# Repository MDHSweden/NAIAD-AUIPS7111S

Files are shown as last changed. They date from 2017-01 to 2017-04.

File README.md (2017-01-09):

# AUIPS7111S

> The [AUIPS7111S](http://www.farnell.com/datasheets/1441780.pdf) is a fully protected four terminal high
> side switch. It features current sensing, over-current, over-
> temperature, ESD protection and drain to source active
> clamp. When the input voltage Vcc - Vin is higher than the
> specified threshold, the output power Mosfet is turned on.
> When the Vcc - Vin is lower than the specified Vil
> threshold, the output Mosfet
> is turned off. The Ifb pin is
> used for current sensing.

## AUIPS7111S Test curcuit

This is a prototype sub part of PDB.

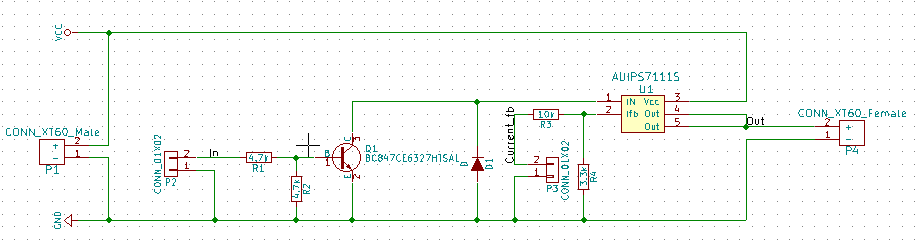
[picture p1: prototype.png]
Image of prototype


The voltage across R4 is `V_R4 = R_4 * I_fb`. So we can configurate the R4 to set the current sense voltage propotional constant to current draw.

`V_R4 = R_4 * I_VCC_Out / Ratio`

### Parts

| Part  | Function  |
|-----|---|
| P1  | Power input |
| P4  | Power output  |
| R1  | Current limiter for BJT. Prevent destroying the BJT or waste power.  |
| R2  | Passive pull down for BJT. We want to make sure the U1 is passively off in case of signal `In` is high impedance.  |
| D1  | Protection for BJT in case of reverse current.  |
| U1  | Switch, current sensing.  |
| R4  | Voltage gain for current sensing. Resistance from `I_fb` to `GND` is max 1.5k [datasheet](http://www.farnell.com/datasheets/1441780.pdf)  |
| R3  | Protection for U1. Resistance from `I_fb` to `GND` is max 1.5k [datasheet](http://www.farnell.com/datasheets/1441780.pdf)  |
| P2  | Input. Connector to control the U1. |
| P3  | Output. Current feedback. |

### Truth table
| `P2_In`  | `U1`  |
|---|---|
| High | On |
| Low | Off |
| High impedance | Off |

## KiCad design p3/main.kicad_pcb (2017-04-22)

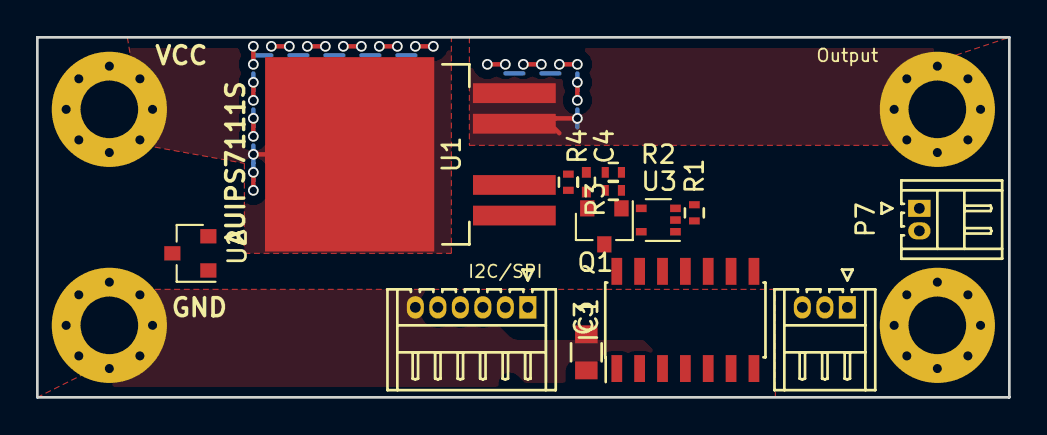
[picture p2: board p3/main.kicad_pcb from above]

Board: 2 copper layers, 54.0 x 20.0 mm, 18 parts (0 on the bottom side), 15 nets.

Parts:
C3: 10uF; C_0805
C4: 1uF; C_0402
IC1: ATTINY84-S; SOIC-14_3.9x8.7mm_Pitch1.27mm
P1, P4, P5, P6: CONN_01X01; MountingHole_3.2mm_M3_Pad_Via
P2: CONN_01X06; Hirose_DF13-06P-1.25DS_06x1.25mm_Angled
P3: CONN_01X03; Hirose_DF13-03P-1.25DS_03x1.25mm_Angled
P7: CONN_01X02; Hirose_DF13-02P-1.25DS_02x1.25mm_Angled
Q1: BSS138; SOT-23
R1, R2: 4.7k; R_0402
R3: 10k; R_0402
R4: 3.3k; R_0402
U1: AUIPS7111S; TO-263-!3
U2: LM3480-5.0; SOT-23
U3: 74LVC1G08; SOT-353

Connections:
+5V: C3.1, IC1.1, P2.5, P3.2, U2.1, U3.5
/Current_Feedback: IC1.12, R3.1
/ENB1: IC1.10, U3.1
/ENB2: P3.3, R1.1, U3.2
/IN: Q1.3, U1.1
/Ifb: C4.1, R3.2, R4.1, U1.2
/MISO: IC1.8, P2.3
/Out: P5.1, U1.4, U1.5
/PWM1: IC1.5, P7.2
/RESET: IC1.4, P2.2
/SCL/SCK: IC1.9, P2.4
/SDA/MOSI: IC1.7, P2.1
GND: C3.2, C4.2, IC1.14, P2.6, P3.1, P4.1, P6.1, P7.1, Q1.2, R1.2, R2.2, R4.2, U2.3, U3.3
unnamed: Q1.1, R2.1, U3.4
VCC: P1.1, U1.3, U2.2

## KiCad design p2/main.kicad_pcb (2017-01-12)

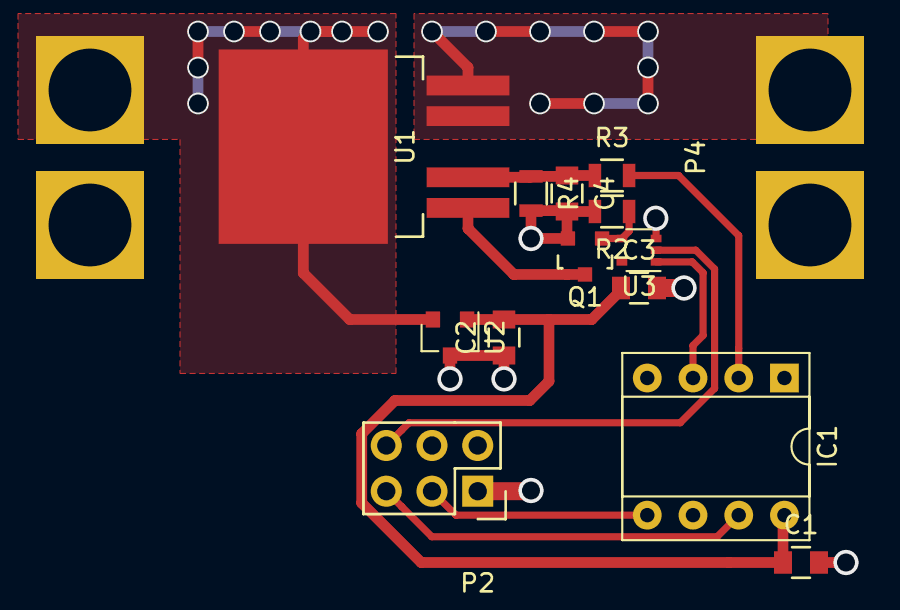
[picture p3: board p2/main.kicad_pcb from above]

Board: 2 copper layers, 15 parts (0 on the bottom side), 12 nets.

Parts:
C1, C2, C3: 10uF; C_0805
C4: C; C_0805
IC1: ATTINY45-P; DIP-8_W7.62mm_Socket
P1, P4: CONN_XT60; XT60
P2: CONN_02X03; Socket_Strip_Straight_2x03
Q1: BSS138; SOT-23
R2: 4.7k; R_0805
R3: 10k; R_0805
R4: 3.3k; R_0805
U1: AUIPS7111S; TO-263-!3
U2: LM3480-5.0; SOT-23
U3: 74LVC1G08; SOT-353

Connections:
+5V: C1.1, C2.2, C3.1, IC1.8, U2.1, U3.5
/ENB: P2.6, U3.2
/IN: Q1.3, U1.1
/Ifb: C4.1, R3.1, R4.1, U1.2
/Out: P4.2, U1.4, U1.5
/SCL: IC1.7, P2.5
/SDA: IC1.5, P2.3
GND: C1.2, C2.1, C3.2, C4.2, IC1.4, P1.1, P2.1, P4.1, Q1.2, R2.2, R4.2, U2.3, U3.3
unnamed: IC1.2, R3.2
unnamed: IC1.3, U3.1
unnamed: Q1.1, R2.1, U3.4
VCC: P1.2, U1.3, U2.2

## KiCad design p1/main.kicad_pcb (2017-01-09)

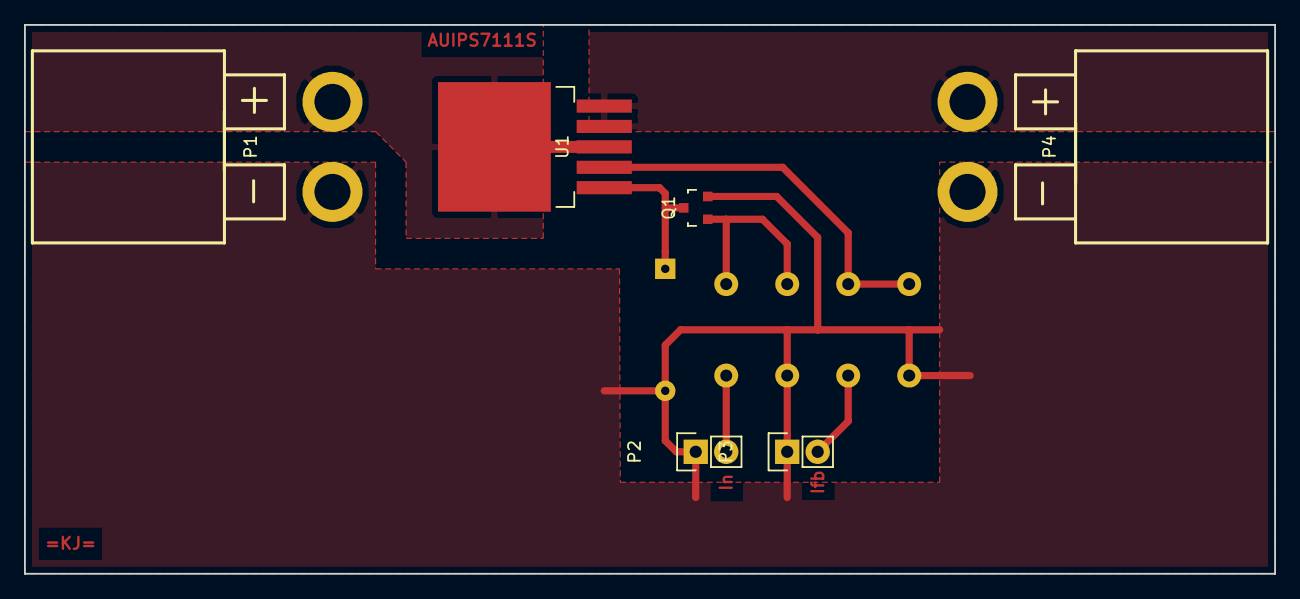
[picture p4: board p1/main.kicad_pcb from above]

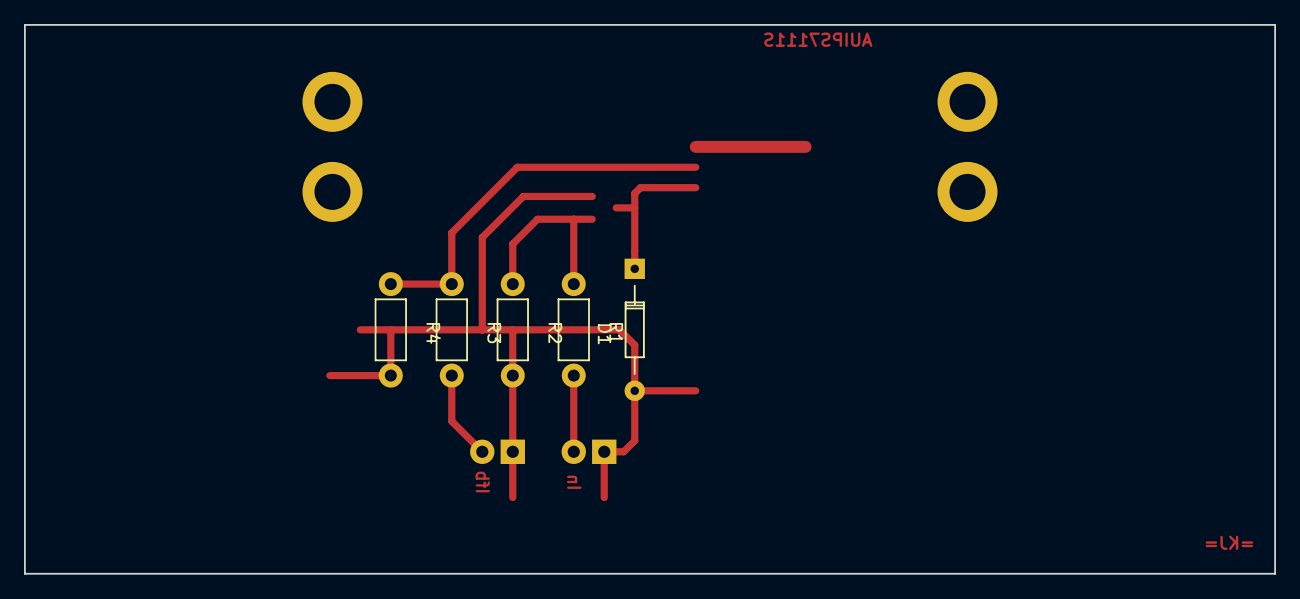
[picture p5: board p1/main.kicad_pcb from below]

Board: 2 copper layers, 104.1 x 45.7 mm, 11 parts (5 on the bottom side), 8 nets.

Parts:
D1: D; Diode_DO-35_SOD27_Horizontal_RM10
P1: CONN_XT60_Male; CONN_XT60_Male1_Horizontal
P2, P3: CONN_01X02; Pin_Header_Straight_1x02
P4: CONN_XT60_Female; CONN_XT60_Female_Horizontal
Q1: BC847CE6327HTSA1; SOT-23
R1, R2: 4.7k; Resistor_Horizontal_RM7mm
R3: 10k; Resistor_Horizontal_RM7mm
R4: 3.3k; Resistor_Horizontal_RM7mm
U1: AUIPS7111S; TO-263-5Lead

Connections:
/Current_fb: P3.2, R3.2
/In: P2.2, R1.2
/Out: P4.2, U1.4, U1.5
GND: D1.2, P1.1, P2.1, P3.1, P4.1, Q1.2, R2.2, R4.2
unnamed: D1.1, Q1.3, U1.1
unnamed: Q1.1, R1.1, R2.1
unnamed: R3.1, R4.1, U1.2
VCC: P1.2, U1.3
